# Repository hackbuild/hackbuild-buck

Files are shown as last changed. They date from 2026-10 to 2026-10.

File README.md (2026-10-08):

# BUCK

A 3D printed talking deer head. Send it text from anywhere and it says it out loud, moving its jaw in time with the vowels.

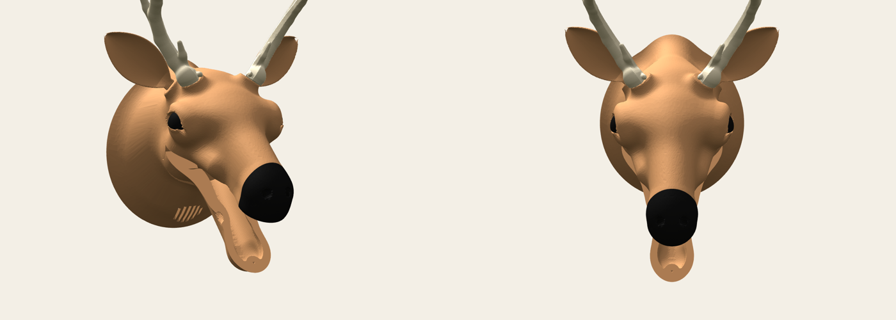
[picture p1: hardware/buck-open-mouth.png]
BUCK with its mouth open


BUCK runs on an ESP32-C3 SuperMini with a 9 g servo for the jaw and a small I2S amp. The voice is SAM, the 1982 Software Automatic Mouth, rendered on the chip. Messages come in over USB serial, [CLASP](https://clasp.to), or MQTT, and anyone with curl can make it talk.

One of them hangs on the wall at [HeatSync Labs](https://www.heatsynclabs.org) in Mesa, Arizona. This repo has everything to talk to that one, and everything to print, wire, and program your own.

## Talk to the BUCK at HeatSync

From a terminal, with the curl that ships on macOS and most Linux distros:

```
curl -d "hello from the internet" mqtt://relay.clasp.chat/hackbuild/buck/heatsync/say
```

From a browser: [hackbuild.github.io/hackbuild-buck](https://hackbuild.github.io/hackbuild-buck/) has a text box, a voice picker, and a live view of what BUCK is saying.

From code, with the [CLASP JavaScript client](https://www.npmjs.com/package/@clasp-to/core):

```js
import { Clasp } from '@clasp-to/core';
const buck = new Clasp('wss://relay.clasp.to', { name: 'my app' });
await buck.connect();
buck.emit('/hackbuild/buck/heatsync/say', 'hello deer');
```

From Python, with nothing to install:

```
python3 tools/buck.py say "hello deer"
python3 tools/buck.py say "hello deer" --voice robot
python3 tools/buck.py watch
```

A few things to know before you send:

- BUCK takes 200 characters per message. Longer text is cut.
- It takes four messages at once, then one every three seconds. Extra messages are dropped, not queued.
- Plain English works best. Numbers are read digit by digit, so "10" comes out as "one zero".
- Voices are `sam`, `elf`, `robot`, `stuffy`, `oldlady`, and `et`. Send one to `/hackbuild/buck/heatsync/voice`.
- It is a deer on a wall in a room full of people. Be someone they would want to hear from.

The HeatSync BUCK also announces the lab calendar: an hour before each event, and at 9:30 and 9:45 PM before closing. That runs separately, in [hackbuild/buck-announcer](https://github.com/hackbuild/buck-announcer).

[docs/PROTOCOL.md](docs/PROTOCOL.md) has every address, payload, status value, and limit, with examples for curl, mosquitto, Python, JavaScript, and raw CLASP frames.

## Build your own

You need a 3D printer, about 240 g of PETG, an ESP32-C3 SuperMini, an SG90 servo, the NULLLAB NS4168 amp kit, a USB-C charger, and a soldering iron. [docs/BUILD.md](docs/BUILD.md) walks through the whole thing:

1. Print the parts from `hardware/`. Nothing needs supports.
2. Wire the board, servo, and amp. Five wires and two components.
3. Flash the firmware with [PlatformIO](https://platformio.org).
4. Set WiFi and a name over serial.
5. Calibrate the jaw.

Your BUCK gets its own address, `hackbuild/buck/<your id>/say`, on the same public relays, so it works from anywhere the moment it joins WiFi.

## What is in here

```
src/            firmware: speech, jaw, console, network links
lib/buckproto/  CLASP and MQTT codecs and the text filter, no Arduino, unit tested
lib/sam/        SAM speech synth, with a hook that drives the jaw
test/           host tests: pio test -e native
tools/buck.py   send, watch, and serial console from your computer
web/            the talk page published to GitHub Pages
hardware/       STL and 3MF print files, print card, the BUCK bench design tool
docs/           BUILD.md, PROTOCOL.md, FIRMWARE.md
```

[docs/FIRMWARE.md](docs/FIRMWARE.md) covers how the firmware is put together: the four tasks, how the jaw reads SAM's formants, what happens when WiFi drops or the board crashes, and every serial command.

## License

The firmware links SAM, which is GPL-3.0, so this repository is GPL-3.0. See [LICENSE](LICENSE). SAM is by Don't Ask Software (1982), reverse engineered to C by Sebastian Macke, and ported to the ESP8266 and ESP32 by Earle F. Philhower III.

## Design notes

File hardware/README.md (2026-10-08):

# Print files

| file | what it is |
|---|---|
| `buck-plates-3mf.zip` | four plates, one per filament: brown (head, jaw, ears), bone (antlers), black (nose, eyes), walnut (plaque, hooks, pivot pin) |
| `buck-one-colour.3mf` | every part on one 256 x 256 bed for a single filament |
| `buck-stl.zip` | each part as a single body STL, plus `print-card.txt` and `design.json` |
| `print-card.txt` | orientation, fits, hardware, and assembly on one page |
| `design.json` | the BUCK bench settings these files came from; load it in the bench to start from this head |
| `buck-bench.html` | the BUCK bench design tool, one offline HTML file: shape the head, check the fit audit, export plates |
| `source/buck-bench-src.zip` | the bench's source (`build.py` assembles `buck-bench.html`) |
| `buck-open-mouth.png` | render of the finished head |

The print card's wiring section lists an ESP32-S3 SuperMini pinout. This repo's firmware runs on the ESP32-C3 SuperMini, which has the same footprint; wire it as shown in [docs/BUILD.md](../docs/BUILD.md).

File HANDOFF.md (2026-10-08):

# buck, handoff

## what it is

A 3D printed talking deer head. ESP32-C3 SuperMini, SG90 jaw servo, NULLLAB NS4168 I2S amp. Text arrives over USB serial, CLASP over WebSocket, or MQTT; SAM speaks it on the chip and the jaw follows each frame's first formant. One hangs at HeatSync Labs and anyone can make it talk with curl.

Read `RULES.md` first. It is absolute and wins over this file.

## deployments

| what | where |
|---|---|
| repo | https://github.com/hackbuild/hackbuild-buck |
| talk page | https://hackbuild.github.io/hackbuild-buck/ (GitHub Pages, `web/`, `.github/workflows/pages.yml`) |
| the HeatSync head | id `heatsync`, WiFi `heatsynclabs`, flashed from the `heatsync` env on 2026-10-07 |
| CLASP door | `wss://relay.clasp.to`, open, no MQTT (DigitalOcean App Platform behind Cloudflare) |
| MQTT door | `relay.clasp.chat:1883`, open; its CLASP WebSocket side needs a token |
| curl | `curl -d "hello" mqtt://relay.clasp.chat/hackbuild/buck/heatsync/say` |
| calendar announcements | https://github.com/hackbuild/buck-announcer, a Cloudflare Worker that sends lines to this head over CLASP; verified on the head 2026-10-07 |

## where it stands, 2026-10-07

Firmware 1.2.0 is on the HeatSync head and verified on the HeatSync WiFi:

- curl over MQTT, `tools/buck.py` over MQTT and CLASP, and the `@clasp-to/core` 4.3.2 SDK all made it speak; the talk page loaded and showed live status
- after seven idle minutes, messages still arrived on both links (this failed before the heartbeat; see "things found in CLASP")
- heartbeats come back on both links every 45 s
- a 14 second line full of phone numbers played to the end (the reciter split)
- status (`online`, `speaking`, `said`, `info`) reached subscribers on both relays, late joiners included; the jaw stream ran at about 15 Hz
- the rate limiter passed 4 of a burst of 6
- 20 host tests pass, including 200,000 random frames through the CLASP decoder; CI builds both environments on every push

1.2.0 fixes the crash a line of the letter o caused: SAM's `InsertBreath` looped forever on a long word, starving the network until the watchdog rebooted the board. Fuzzing SAM under AddressSanitizer then found five more hangs and overruns in it. All are fixed (`lib/sam/README.md` lists them), `test/test_sam` keeps them fixed, 80,000 random lines ran clean on the host, and 60 and 200 o's now play on the head.

An independent review of the firmware found ten problems, all fixed in the same pass: reciter overflow cutting off the ends of lines, watchdog overrun on weak WiFi, safe mode that never recovered, a fragile MQTT heartbeat probe, `speaking` dropping early, oversize messages discarded instead of cut, a tripled backoff on one failed send, a servo cache that skipped writes after `/release`, a jaw jump out of a hold, and a possible synth stall.

The head's voice is back on the defaults, `sam` (speed 72, pitch 64), as of 2026-10-08.

The head's saved volume is 30. On the bench it runs from a bus powered USB hub, and at 50 it browned out at the first syllable of every line; at 30 a 14 second sentence played clean. On a 1 A charger with the servo capacitor it should take 50 or more: `/vol 50`.

## decisions and why

- Two relays. relay.clasp.to is the only open CLASP WebSocket relay; relay.clasp.chat is the only one with MQTT open, and curl speaks MQTT. Guest tokens on relay.clasp.chat are scoped to `/chat/**`, so one relay could not serve both. curl over `wss://` cannot work: the relay drops PUBLISH before HELLO and reads one frame per WebSocket message.
- Own WebSocket client and codecs. The CLASP Arduino library (`bindings/arduino`, 1.0.0, on every branch, unpublished) speaks TCP only, and the relays only take WebSocket. The codec follows `crates/clasp-core/src/codec.rs`, with test vectors captured from the live relay.
- Heartbeat on both links. Because of the idle-session bug above, each link publishes `status/beat` every 45 s and expects it back through its own subscription; 140 s without one means reconnect. CLASP gets the beat back through the SET echo. MQTT does not echo, so a short lived second connection publishes the beat. Keepalive pings cannot catch the bug: the relay answers them the whole time.
- Ignore replays. relay.clasp.chat replays every stored MQTT topic before SUBACK with retain cleared, so BUCK skips anything on a topic until its SUBACK. CLASP snapshots are skipped too.
- ESP32-C3, not S3. The print card and bench say S3 SuperMini; the board on the wall is a C3 (esptool says so), wired servo 4, BCLK 5, LRCLK 6, DIN 7.
- Jaw calibration on the HeatSync head: it was assembled at the servo's end stop with the jaw fully open. The BUCK geometry (shaft out the right cheek, jaw opens clockwise looking at the shaft) put open at the short-pulse end. Probing with single pulses (at most about 12 degrees each, under the 22 degree swing) confirmed it, and closed was found from the open side in small steps. Result: open 500 us, closed 730 us.
- Talking stops 10 us short of closed. Driving the servo into the contact point stalls it and browned out the board on USB power.
- WiFi TX power 8.5 dBm. Cuts radio bursts from about 300 mA, and is the known fix for the SuperMini's antenna. Full power plus servo plus amp browned out the board.
- Network settings save and reboot instead of applying live, so no task ever reads a half written string.
- GPL-3.0 for the whole repo, because SAM is GPL.

## open questions

- Anyone on the internet can make the head say anything. The rate limit stops floods, not words. A word filter, an allow list, or `/remote off` during events are options; nothing is filtered now. This is a call for HeatSync.
- The head runs off a bus powered USB hub on the bench. On the wall it needs a 1 A charger. The 10 k pull-down on GPIO4 and the servo capacitor may not be fitted yet; both are in docs/BUILD.md.
- An HTTP bridge on relay.clasp.to (`clasp http`, `POST /v1/emit/...`) would allow a plain `curl -X POST https://...` that works without MQTT. Today the relay answers every HTTP path with `ok`.

## things found in CLASP along the way

Worth fixing upstream in lumencanvas/clasp:

- Idle sessions lose their subscriptions without being closed. `clasp-router` `start_session_cleanup_task` removes a session idle for `session_timeout` (300 s) and its subscriptions, but never closes the transport, and `last_activity` only moves when the router sends to the client (`Session::send`, `try_send`). Client sends and WebSocket pings do not count. A listener that rarely receives anything goes deaf after five minutes while its socket stays up and pongs keep coming. Both relays showed it: BUCK heard nothing for 48 minutes on 2026-10-07 with both links "ready". The fix belongs in the router: close the transport when a session times out, and count inbound traffic as activity.
- relay.clasp.chat's MQTT side never delivers a client's own publishes back to it.
- relay.clasp.chat's MQTT bridge stores non-retained publishes and replays them before SUBACK with the retain flag cleared.
- docs.clasp.to's LLM reference shows `subscribe` callbacks as `(address, value)`; `client.ts` has `(value, address)`.
- The protocol doc's SET example says payload length 0x1B; its own bytes are 26 (0x1A).
- `clasp pub` 4.5.0 prints "OK Published" and then logs "Server connection not yet implemented".
- The Arduino library's value codes differ from the protocol doc's (bool as 0x01 plus a byte), though they match the Rust codec.

## this machine

- PlatformIO Core was upgraded to 6.2.0; pioarduino 55.03.312-1 needs it.
- The disk was full during the first build. `~/.platformio/packages/framework-arduinoespressif32-libs` holds only the `esp32c3` and `hosted` folders of core 3.3.12's libs, marked installed by hand. Building for any other ESP32 with this platform will fail until it is reinstalled with space free: `pio pkg uninstall -g -t framework-arduinoespressif32-libs`, then build again.
- The CLASP source checked out at `~/Projects/lumencanvas/clasp` (branch relay-scaling) is where the relay, codec and Arduino library were read from.

## running locally

```
pio test -e native                         # host tests, must pass before a commit
pio run -e buck -e heatsync                # both firmware builds, must pass before a commit
pio run -e heatsync -t upload              # flash the HeatSync head
pio device monitor                         # serial console
python3 tools/buck.py say "hi"             # MQTT, stdlib only
python3 tools/buck.py watch --via clasp    # needs websockets
```

Opening the C3's USB serial with RTS high and DTR low resets it. `tools/buck.py console` holds RTS low.

Before flashing an assembled head, park the jaw part open with `/jaw 50`. The reset during upload drives the servo line high briefly, which pushes toward closed.

## commits

Author is Moheeb Zara <hackbuildvideo@gmail.com>. No trailers, no AI attribution, imperative lowercase subjects under 60 characters. See `RULES.md`.

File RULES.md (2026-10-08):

# Rules for working in this repository

These rules are absolute. They apply to every file, every commit, and every generated string, including code comments, serial log lines, status strings, and the web page. Where any other document disagrees with this one, this one wins.

## Attribution

- Never add Claude, any AI assistant, or any AI tool as an author, co-author, contributor, or credit of any kind. Not in commit messages, not in Co-Authored-By trailers, not in comments, not in documentation.
- Commit messages carry no trailers, no badges, no generated-with lines. Subject in the imperative, lowercase, under 60 characters. Body only when the change needs explaining, wrapped at 72 columns.
- Author is Moheeb Zara <hackbuildvideo@gmail.com>.

## Language

- No emojis, anywhere.
- No em dashes or en dashes. Use commas, periods, or the word "to" for ranges.
- No "it is not x, it is y" construction or its variants.
- No closing line that restates the point.
- No exclamation marks in prose, logs, or UI copy.
- No marketing adjectives: seamless, powerful, robust, comprehensive, beautiful, elegant, and their kin. Say what it does.
- No filler openers: "Let's", "Simply", "Just", "Note that".
- Log lines and UI copy are lowercase and terse, and name the failure: "no WiFi set, send: /wifi <ssid> <password>" beats "error".
- Never claim a capability the hardware does not have.

## Firmware

- No heap allocation per message. Buffers are sized at compile time or allocated once at boot.
- Every blocking network call has a deadline.
- Only the player task drives the servo. Only the net task touches sockets.
- The jaw never leaves the calibrated range outside the explicit calibration commands.
- `pio test -e native` and `pio run -e buck -e heatsync` pass before a commit.

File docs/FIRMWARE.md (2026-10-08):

# How the firmware works

BUCK's firmware is Arduino on ESP-IDF, built with PlatformIO for an ESP32-C3 at 160 MHz. The C3 has one core, so everything here is about priorities and bounded work.

## Tasks

```
serial --+
CLASP  --+--> remote gate --> text queue --> synth task --> stream buffer --> player task --> I2S amp
MQTT   --+    (clean, limit)  (8 lines)      (SAM)          (8 KB, 370 ms)    (20 ms blocks)  +-> servo
                                               |                                ^
                                               +--> jaw events, timestamped ----+
                                               +--> "said" event --> net task --> status on both relays
```

| task | priority | stack | job | file |
|---|---|---|---|---|
| player | 5 | 4 KB | stream buffer to I2S, jaw to servo, console jaw commands | `src/speech.cpp` |
| synth | 3 | 8 KB | text to SAM to samples and jaw events | `src/speech.cpp` |
| net | 2 | 8 KB | WiFi, CLASP link, MQTT link, status | `src/net/net.cpp` |
| loop | 1 | 8 KB | serial console | `src/console.cpp` |

The player outranks the synth, and both outrank the network. A TLS handshake or a stalled socket can slow a link down, but it cannot take time from the 20 ms audio blocks. WiFi's own tasks run above all of these, as ESP-IDF sets them.

Only the player task touches the servo. The console asks for jaw moves through a small queue (`jawCommand()`), so nothing ever fights over the LEDC channel.

Only the net task touches sockets. Links, codecs and buffers have one owner and need no locks.

## Speech and the jaw

SAM renders speech in 10 ms frames. Each frame carries the formants that make its sound, and the first formant, F1, tracks how open a real mouth is: high for "ah", low for "ee" and "oo", and lowest for m, b and p. `lib/sam/src/render.c` has one change from upstream, a `samFrameHook` called at the start of every frame with F1 and the voicing amplitude. The synth task turns that into an openness value:

```
voiced frame:    open = clamp((F1 - 6) / (24 - 6)) * clamp(A1 / 13)
unvoiced frame:  open = 0.15     s, sh, f, th, ch
silence:         open = 0        A1 is 0, which also covers the closure of p, t, k
```

Each value is stamped with its sample position in the stream and queued. The player writes 20 ms blocks to I2S, and for each block takes the widest frame due by the end of that block plus `/lead` ms. It smooths that with a 30 ms attack and a 70 ms release and moves the servo.

The I2S DMA holds about 60 ms, so the servo hears about the jaw roughly 60 ms before the speaker plays the sound. That covers the SG90's lag. Every line starts with 60 ms of silence so the first syllable gets the same head start.

While talking, "closed" is 10 us short of the calibrated closed end (`JAW_CLOSED_MARGIN_US`). A servo held exactly at the contact point pushes against the head and draws stall current, which on a USB supply is enough to brown out the board. After 0.6 s of quiet the PWM detaches entirely.

Talking moves are rate limited to 60 us per 20 ms block (`JAW_SLEW_US`), about 5 degrees. That caps the servo's current spikes and turns a jump from a held position into a quick glide.

Everything reaches SAM through `lib/sam/src/sam_say.c`. `samTame` keeps the input to what SAM's reciter knows, caps any repeated character at three ("soooooo" says "sooo") and splits words longer than 14 characters. `samSay` cuts lines into pieces; SAM's reciter quietly stops once its phoneme output passes 120 characters, and every digit is a word, so a phone number fills that fast. It checks where the reciter's end marker landed and, if a piece overflowed, splits it at the space nearest the middle and tries each half.

SAM itself is old C with byte-sized indexes into fixed arrays. A line of the letter o hung the deer on 2026-10-07 (an endless loop in `InsertBreath`), and fuzzing under AddressSanitizer found five more ways to hang or overrun it. All are fixed and listed in `lib/sam/README.md`, and `test/test_sam` runs the same `samTame`/`samSay` path on the host under the sanitizers, with an alarm on every input so a hang fails the test.

The jaw never goes outside the calibrated range during speech, `/jaw` or `/sweep`. Only `/servo` and `/probe`, the calibration tools, can reach the full 500 to 2500 us, and `/servo` glides at about 30 degrees a second.

## Memory

Everything is allocated once, at boot:

| what | size |
|---|---|
| text queue, 8 lines of 400 characters | 3.2 KB |
| audio stream buffer | 8 KB |
| jaw event queue, 128 events | 1 KB |
| SAM working memory | 3.7 KB |
| CLASP link buffers (rx 2 KB, tx 640 B, frame 600 B) | 3.3 KB |
| MQTT link buffers (rx 512 B, tx 512 B) | 1 KB |
| task stacks | 28 KB |

Static RAM use is 49 KB of 320 KB. With WiFi up and a TLS session open, about 95 KB of heap stays free, and the lowest it has been is reported as `minHeap` in `status/info`. No code path allocates per message. The codecs write into caller buffers and point into received frames instead of copying.

The TLS client does allocate when it connects. Before each attempt the CLASP link checks that the largest free block is at least 45 KB and skips the attempt if not, so a fragmented heap delays a reconnect instead of crashing it.

## When things go wrong

| failure | what BUCK does |
|---|---|
| WiFi drops | both links stop; WiFi auto reconnect runs, with a fresh `WiFi.begin` every 30 s; after 20 minutes offline it reboots, once it is quiet |
| relay unreachable or refuses | that link backs off 2 s, 4 s, 8 s and so on up to 2 minutes, plus up to 25 percent jitter; the other link carries on |
| link goes silent | WebSocket ping or MQTT PINGREQ every 20 s when idle; nothing heard for 65 s means reconnect |
| relay drops the subscription but keeps the socket | heartbeat: every 45 s each link sends itself a message through its own subscription (CLASP by SET echo, MQTT from a short lived second connection); no beat back for 140 s means reconnect. Pings cannot catch this, the relay keeps answering them |
| malformed CLASP frame | ignored, link stays up; the decoder checks every length and nesting depth (fuzzed with 200,000 random frames in the tests) |
| malformed MQTT stream | link is dropped and reconnected |
| oversize MQTT packet | read to its end so the stream stays in sync, and delivered cut to the 512 byte buffer; the text is then cut to 200 characters as usual |
| oversize WebSocket message (over 2 KB) | read off the wire and dropped, counted |
| flood of messages | token bucket (4, then 1 per 3 s) and a cap of 4 waiting network lines |
| old messages replayed by a relay | ignored: CLASP snapshots are skipped, MQTT messages before SUBACK are skipped |
| a task hangs | task watchdog, 60 s, on the player, synth, net and loop tasks; the chip resets with a backtrace on serial. Every network connect is bounded at 8 s plus the TLS handshake, and every later socket write at 3 s (plain) or 8 s (TLS), with the watchdog fed between steps |
| crashes in a loop | a counter in RTC memory; three crash resets in a row boot into safe mode with networking off, so serial still works. Five crash-free minutes turn networking back on by themselves; `/reboot` clears the count and boots normally straight away |
| brownout | the chip resets; `status/info` reports `"reset":"brownout"` so it shows up remotely |
| nobody reading USB serial | the CDC TX timeout is zero, so logging never blocks |

## Serial console

115200 baud on the USB port. Lines starting with `/` are commands; anything else is spoken.

| command | does |
|---|---|
| `/vol <0-100>` | volume, saved |
| `/voice <name>` | `sam` `elf` `robot` `stuffy` `oldlady` `et`, saved |
| `/speed` `/pitch` `/throat` `/mouth <1-255>` | SAM's four voice controls, saved |
| `/stop` | cut the current line and clear the queue |
| `/tone [hz] [ms]` | test tone |
| `/jaw <0-100>` | hold the jaw at a percent open for 3 s |
| `/sweep` | closed, open, closed over 3 s |
| `/open <us or deg>` `/closed <us or deg>` | calibration ends; over 180 means microseconds; saved |
| `/lead <ms>` | jaw lead over the sound, default 10, saved |
| `/servo <us>` | glide to a raw pulse and hold it until `/release` or speech |
| `/probe <us> [n]` | n single pulses, then let go |
| `/release` | stop driving the servo |
| `/wifi <ssid> <password>` | save and reboot; the SSID cannot contain spaces, the password can |
| `/id <name>` | 1 to 31 letters, digits, `-` or `_`; save and reboot |
| `/clasp <wss://host or off>` | CLASP relay; save and reboot |
| `/mqtt <host[:port] or off>` | MQTT broker; save and reboot |
| `/tls on or off` | check the relay's certificate (on by default); save and reboot |
| `/remote on or off` | accept network messages; saved |
| `/net` | WiFi and link status, counters |
| `/status` | firmware, calibration, voice, heap |
| `/reboot` `/factory` | restart; wipe saved settings and restart |

Network settings reboot on change because the network task reads them once at start. That keeps a half written string from ever reaching a socket.

## Settings

NVS namespace `buck`. Missing keys fall back to the build defaults in `platformio.ini`.

| key | type | default |
|---|---|---|
| `open` `closed` | int, us | `BUCK_DEFAULT_OPEN_US`, `BUCK_DEFAULT_CLOSED_US`, 0 means uncalibrated |
| `lead` | int, ms | 10 |
| `vol` | int | 50 |
| `voice` | string | `sam` |
| `speed` `pitch` `throat` `mouth` | int | 72, 64, 128, 128 |
| `id` | string | `BUCK_DEFAULT_ID`, else `buck-` and the MAC |
| `ssid` `pass` | string | `BUCK_DEFAULT_SSID`, `BUCK_DEFAULT_PASS` |
| `clasp` | string | `wss://relay.clasp.to` |
| `mqtt` `mqttport` | string, int | `relay.clasp.chat`, 1883 |
| `tls` `remote` | bool | true, true |

## TLS

The CLASP link checks the relay's certificate against the roots in `src/net/ca_roots.h`: Google Trust Services R1, R3 and R4, and ISRG X1 and X2. relay.clasp.to currently chains to GTS Root R4 through Cloudflare. The earliest of these roots expires in 2035. If the relay moves to a CA outside that list, the CLASP link logs a connect failure and MQTT keeps working; add the new root, or `/tls off` as a stopgap.

## Build environments

| env | for |
|---|---|
| `buck` | your own BUCK; nothing preset |
| `heatsync` | the HeatSync Labs head: id `heatsync`, its WiFi, and its jaw calibration (open 500 us, closed 730 us) |
| `native` | host unit tests: `pio test -e native` |

The platform is pinned to pioarduino 55.03.312-1, which is Arduino core 3.3.12 on ESP-IDF 5.5.5, and needs PlatformIO Core 6.2 or newer.

## Power

Peak draw is the amp, the servo and the WiFi radio together, and the amp is the largest part. Measured on the HeatSync head running from a bus powered USB hub: talking at `/vol 50` browned out at the first syllable, the jaw alone at `/vol 0` did not, and `/vol 30` got through a 14 second sentence clean.

The firmware already trims what it can: WiFi transmit power is 8.5 dBm (radio bursts drop from about 300 mA, and the SuperMini's antenna likes it), talking never presses the jaw into its stop, and jaw moves are rate limited. The rest is hardware: a USB charger of 1 A or more and a 470 to 1000 uF capacitor at the servo. On weak power, keep `/vol` around 30.

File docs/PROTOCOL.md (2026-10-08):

# Talking to BUCK

Every BUCK listens on two public relays at once and reports what it is doing on both. This page is the full contract: addresses, payloads, limits, and what comes back.

## Two doors, one deer

[CLASP](https://clasp.to) is a signal routing protocol: clients connect to a relay, publish to addresses that look like `/a/b/c`, and subscribe to patterns. BUCK keeps two connections open, one to each of two CLASP relays:

| door | relay | who it is for |
|---|---|---|
| CLASP over WebSocket | `wss://relay.clasp.to` | browsers, the CLASP SDKs, anything that speaks CLASP |
| MQTT 3.1.1 over TCP | `relay.clasp.chat:1883` | curl, mosquitto, any MQTT client |

MQTT stands for Message Queuing Telemetry Transport, a small publish and subscribe protocol that curl happens to speak. The MQTT door is the MQTT bridge built into the CLASP relay, so an MQTT topic `hackbuild/buck/heatsync/say` is the CLASP address `/mqtt/hackbuild/buck/heatsync/say` on that relay.

The two relays are separate routers. A message sent on one is not visible on the other, so pick one door and read status from the same one. Neither needs an account.

## Addresses

Each BUCK has an id. The one at HeatSync Labs is `heatsync`. Yours is whatever you set with `/id`, or `buck-` plus the last six hex digits of its MAC address.

| what | CLASP address (relay.clasp.to) | MQTT topic (relay.clasp.chat) |
|---|---|---|
| say something | `/hackbuild/buck/<id>/say` | `hackbuild/buck/<id>/say` |
| change voice | `/hackbuild/buck/<id>/voice` | `hackbuild/buck/<id>/voice` |
| status | `/hackbuild/buck/<id>/status/...` | `hackbuild/buck/<id>/status/...` |

## Sending

### say

The payload is the text. In CLASP, send it as a string, either as an event (`emit`) or a param (`set`); BUCK treats both the same, and a number is read out as a number. In MQTT, the payload bytes are the text.

```
curl -d "hello deer" mqtt://relay.clasp.chat/hackbuild/buck/heatsync/say
mosquitto_pub -h relay.clasp.chat -t hackbuild/buck/heatsync/say -m "hello deer"
python3 tools/buck.py say "hello deer"
python3 tools/buck.py say "hello deer" --via clasp
```

```js
// @clasp-to/core 4.3.2, Node or browser
const buck = new Clasp('wss://relay.clasp.to', { name: 'my app' });
await buck.connect();
buck.emit('/hackbuild/buck/heatsync/say', 'hello deer');
```

### voice

The payload is one of `sam`, `elf`, `robot`, `stuffy`, `oldlady`, `et`. Anything else is ignored. A voice set over the network lasts until BUCK reboots; a voice set over serial is saved.

```
curl -d "robot" mqtt://relay.clasp.chat/hackbuild/buck/heatsync/voice
```

### What BUCK does with your text

1. Cleans it: curly quotes become straight ones, emoji and other non-ASCII become spaces, whitespace collapses. Before speaking, a character repeated more than three times is cut to three ("noooooo" says "nooo") and a word longer than 14 characters is split.
2. Cuts it to 200 characters. Over MQTT any length is accepted and cut; over CLASP a frame larger than 2 KB is ignored.
3. Checks the rate limit: a bucket of four messages, refilled at one every three seconds, shared by everyone on both doors.
4. Checks the queue: at most four network messages wait at once.
5. Speaks it, after whatever is already queued.

A message that fails step 3 or 4 is dropped. There is no reply; watch `status/said` to see what made it.

SAM reads English spelling with its own rules from 1982. Short sentences with ordinary words sound best. Digits are read one at a time, so write numbers as words. Punctuation shapes the intonation: a period drops the pitch, a question mark raises it.

## Status

BUCK publishes these whenever they change. On relay.clasp.to they are CLASP params, and on relay.clasp.chat they are MQTT messages with the retain flag. Either way the relay stores the last value, so anyone subscribing late gets the current state straight away.

| leaf | type | meaning |
|---|---|---|
| `status/online` | bool | `true` when the link comes up. MQTT also sets a will of `false`, so the broker flips it if BUCK vanishes. CLASP has no will, so check `info` for freshness |
| `status/speaking` | bool | talking right now |
| `status/said` | string | the line it started speaking most recently |
| `status/info` | string, JSON | refreshed every 60 s, see below |
| `status/jaw` | float 0 to 1, CLASP stream | jaw openness about 15 times a second while talking, then a final 0. Not stored, CLASP only |
| `status/beat` | int (CLASP) or text (MQTT) | BUCK's heartbeat, every 45 s: seconds since boot. See "staying subscribed" below |

`info` looks like this:

```json
{"fw":"1.2.0","id":"heatsync","up":3600,"heap":94816,"minHeap":74560,"rssi":-54,
 "reset":"power","crashes":0,"queue":0,"heard":42,"limited":3,"voice":"sam",
 "clasp":"ready","mqtt":"ready"}
```

`up` is seconds since boot. `clasp` and `mqtt` are the state of each link: `ready`, `handshake`, `waiting` (backing off before a retry), or `off`. `reset` is why it last booted: `power`, `restart`, `usb`, `brownout`, `panic`, `task-wdt`, and a few rarer ones. `heard` and `limited` count network messages since boot.

Watch status:

```
python3 tools/buck.py watch                  # MQTT
python3 tools/buck.py watch --via clasp      # CLASP, needs: pip install websockets
mosquitto_sub -h relay.clasp.chat -t 'hackbuild/buck/heatsync/status/#' -v
```

```js
buck.on('/hackbuild/buck/heatsync/status/**', (value, address) => {
  console.log(address, value);
});
```

The CLASP callback gets `(value, address)` in that order.

## On the wire

You do not need this to use BUCK. It is here for anyone writing a client from scratch.

CLASP v3 frames are binary. Each WebSocket message carries exactly one frame, and the WebSocket subprotocol is `clasp`.

```
53            magic 'S'
41            flags: QoS 1 (bits 7-6), binary encoding (bits 2-0 = 1)
00 2e         payload length, big endian
...           payload
```

A client sends HELLO first and waits for WELCOME:

```
53 41 00 0d   01 01 e0   00 06 "my app"   00 00
              HELLO, version 1, features param+event+stream, name, empty token
```

Then an event with a string value:

```
53 41 00 2e   20 20   00 1c "/hackbuild/buck/heatsync/say"   01 08 00 0a "hello deer"
              PUBLISH, signal event (1 << 5), address, has value, string, text
```

The relay drops a PUBLISH that arrives before HELLO. It also reads one frame per WebSocket message, so two frames in one message lose the second. That rules out sending CLASP straight from `curl wss://`, which is why the curl examples use the MQTT door.

The full codec BUCK uses is `lib/buckproto/src/clasp_codec.cpp`, and `test/test_protocols` has frames captured from relay.clasp.to.

## Staying subscribed

The relays drop a session's subscriptions after five minutes in which the relay has sent that client nothing, and they do it without closing the socket. Pings keep getting answered, so the client looks connected and hears nothing. A listener that rarely gets messages, which is exactly what a deer on a wall is, falls into this.

BUCK guards against it with a heartbeat on each link. Every 45 s it publishes to its own `status/beat` and listens for that message to come back through its subscription:

- on CLASP, the relay echoes a SET to every subscriber of the address, the sender included
- on MQTT, the relay never sends a client its own publishes, so BUCK opens a second, short lived connection, publishes the beat from there, and disconnects

Either way the relay has something to deliver to BUCK every 45 s, which keeps the session active, and the delivery proves the subscription works end to end. If no beat comes back for 140 s, BUCK drops that link and reconnects.

Clients of your own that only listen should do the same, or reconnect every few minutes.

## Relay behaviour worth knowing

- On relay.clasp.chat every MQTT publish is stored, retained or not, and replayed to new subscribers before their SUBACK, with the retain flag cleared. BUCK ignores anything on a topic until its SUBACK arrives, so old messages are never spoken again after a reconnect.
- On relay.clasp.to a CLASP subscriber gets a SNAPSHOT of stored params first. BUCK ignores snapshots for the same reason.
- relay.clasp.chat requires a token for CLASP over WebSocket, and its guest tokens are scoped to `/chat/**`. That is why CLASP clients use relay.clasp.to.

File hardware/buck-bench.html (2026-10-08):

# BUCK.bench

talking trophy head. servo jaw. printed everything else. undo redo open save guide

1HEAD 2GUTS 3MOUNT 4PRINT

STEP 1 HEAD

isofrontsidetopunder

assembledexplodeprint bedpaintx-raysectionhardwarepegboard

BUILDING

CUT X0

prevplate 1next

JAW0 deg talkmicwiggle

## BUCK.bench

a talking white-tail trophy you print, wire and hang on pegboard. an SG90 servo swings the jaw; an ESP32-S3 or RP2040-Zero and the NULLLAB NS4168 kit (amp and its 3W speaker) do the talking from inside the neck; one USB-C cable runs out the back. everything else is printed: eyes, nose, ears, antlers, pivot pin and pegboard hooks. every part is one material, so print each in its own filament or print it all in one and paint it.

1 head

sculpt, eyes, nose, ears, antlers

2 guts

servo jaw, boards, speaker, wiring

3 mount

plaque, edge, pegboard hooks, head screws

4 print

fit audit, filaments, plates, 3MF

pick a starting point; every change rebuilds the parts and reruns the fit audit.

8 point buckfork hornspikedoe

### SCULPT

scalex

muzzlex

neckx

crownx

cheeksx

nose downdeg

wallmm

sculpt changes regrow the skin from its field, a few seconds. the audit tells you if the servo still fits.

### EYES + NOSE

eyes

separatesculpted

eye sizex

eye fitmm

nose

separatesculpted

nose fitmm

separate eyes are almond domes that press into sockets inside the lids; print them in black for a real shine. sculpted puts them in the head for painting. fit is the designed clearance per side; holes print about 0.15 small, so 0.10 gives a light press.

### ANTLERS

nonespikefork8 point

sizex

spreadx

round on top and 45 degrees underneath, so they print flat with no supports and still look round. keyed tenons press into the pedicles.

### EARS

ears

sizex

ears print lying on their flat backs, cup up: the back is a flat plane with a steep bevel to the rim, and the tenon runs down to the bed, so nothing hangs in the air.

next: guts

### JAW

swingdeg

clearancemm

jaw

channelsealedsolid

jaw wallmm

channel: the lower jaw is an even skin opened through the mouth like a real one, a U trough with a thicker lip rim and the tongue groove down the middle (about 47 percent less plastic). sealed keeps a solid mouth face over a closed void. both print mouth face down with no support: the trough floor is tented at 45 degrees to an 8 mm bridge. the hinge, arms, horn groove and pin bore stay solid.

the jaw rides the servo horn on the right and a printed pivot pin on the left, both on one axis. it slides up through the mouth onto the horn, then the pin pushes in through the left cheek and clicks. no screws: the arm's groove keeps the horn on the spline.

### BOARDS

controller

custom l w t

the controller sticks onto a plinth on the left face of the fin with foam tape or hot glue. the plinth is 9 mm wide, narrower than the pin rows, so every pin and edge pad stays free to solder. its USB-C faces the plaque and lines up with the cable slot.

i2s amp: NULLLAB NS4168, 38.4 x 22.4 from the vendor drawing. it lies flat on a shelf above the speaker on two posts whose spigots fill its 4.7 mm holes, held by two M3 x 6 screws. it slides in from the servo horn side, input connector first, so the fin over it is cut back only where that end passes.

### SPEAKER

framemm

ear spanmm

depthmm

conemm

dome proudmm

ear holemm

the kit speaker lies face down on a seat ring in the bottom of the neck and fires down through a grille in the throat. its ears screw to two bosses with M2 pilots. these sizes come off the listing photo, not calipers: measure yours and set frame, ear span and depth, and the seat, bosses and shelf follow.

### WIRING

pins are a suggestion; any free GPIO works. on an S3 keep off strapping pins 0, 3, 45 and 46. the amp's input is the 5 pin PH2.0 lead from the kit: G, V, BCLK, LRCLK, DIN.

next: mount

### PLAQUE

shieldovalrounded

edge

ogeeroundchamfersquare

thicknessmm

neck fillof width

routed line

head on

3 screwssnap

snap overlapmm

the plaque is sized off the neck: neck fill is how much of the plaque width the neck takes. the edge profile is cut in whole layers so it prints exactly.

3 screws: the head slides over the locating lip and three M3 x 16 flat head screws go in from the back of the plaque, countersunk flush, into bosses inside the neck rim (one top, two low). to take the head off, slide the plaque off its hooks and undo three screws. snap: the old two bead snap, no hardware, less secure.

### PEGBOARD

hang with

printed hooksstore peghooksnone

board

1/4 in1/8 in

spacingin

holemm

keyholes

printed hooks are curved prongs: hold one tilted up, put the tip in a hole and roll it down, and it locks behind the board. do two, a whole number of inches apart, then slide the plaque's back channel onto both from the side. the head's weight winds them tighter.

next: print

### FIT AUDIT

### FILAMENTS

print as

per filamentone colour

head, jaw, ears

antlers

eyes

nose

plaque

pin, hooks

per filament: one 3MF per spool, each a plate you print on its own. one colour: everything packed onto as few plates as possible, then paint; the paint view is your guide.

### PRINT

draft meshfine mesh

layermm

bedxmm

slicer profile

write filaments

printer

process

preset

names only, never settings. blank leaves the slicer's selection alone.

no supports anywhere: head rim down, jaw on its mouth, plaque on its back, nose on its cut face, eyes on their backs, ears lying cup up, antlers, pin and hooks flat. parts are nested on their real footprints, so in one colour mode everything goes on a single 256 bed. exports always use the fine mesh.

### EXPORT

3MF plates3MF per partSTL zipprint cardpaint guide

### PARTS

### HARDWARE

### ASSEMBLY

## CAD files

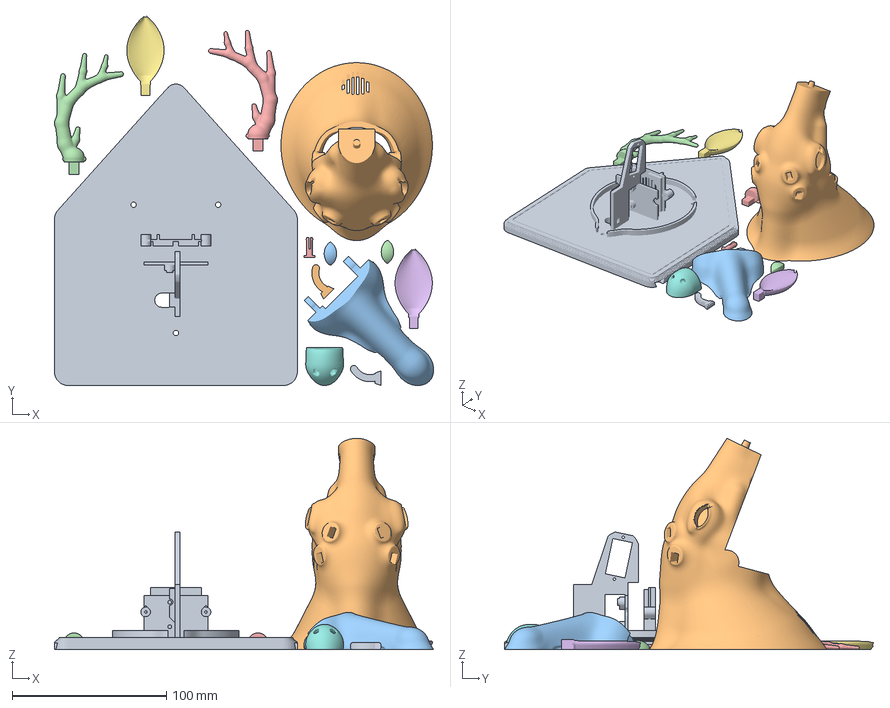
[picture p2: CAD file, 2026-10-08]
hardware/buck-one-colour.3mf
246.0 x 239.3 x 137.0 mm
mount
head
jaw
antler R
antler L
ear R
ear L
nose
hook L
hook R
eye R
eye L
pivot pin

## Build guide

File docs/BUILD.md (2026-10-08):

# Build your own BUCK

Print a deer, give it a voice, and let the internet talk through it.

## Introduction

BUCK is a white-tail trophy head that talks. You print it in four colours of PETG, drop in a microcontroller, a servo, and a tiny amp, and hang it on pegboard. Text you send it comes out of its mouth in SAM's 1982 robot voice, and the jaw moves with the vowels.

In this guide we'll print the parts, wire the electronics, flash the firmware, connect it to WiFi, and calibrate the jaw so it opens and closes in the right places. Plan on a weekend: most of it is print time.

## Prerequisites

Tools:

- A 3D printer with a bed of at least 256 x 256 mm (or print the plates in more pieces)
- A soldering iron and a little solder
- A small Phillips screwdriver
- A computer with [PlatformIO](https://platformio.org), either the VS Code extension or the `pio` command line, Core 6.2 or newer
- About 6 GB of free disk space for the first PlatformIO build

Parts:

| qty | part | notes |
|---|---|---|
| 1 | ESP32-C3 SuperMini | the USB-C one with 8 pins down each side |
| 1 | SG90 or MG90S 9 g servo | with its single arm horn and two mounting screws |
| 1 | NULLLAB NS4168 I2S amp, 3 W kit | comes with the speaker and PH2.0 leads |
| 1 | the kit speaker | 30 mm square frame, ears 39 mm apart, 7.5 mm deep |
| 1 | 470 to 1000 uF electrolytic capacitor, 10 V or more | across the servo power |
| 1 | 10 k resistor | GPIO4 to ground, keeps the jaw still while the board boots |
| 2 | M3 x 6 screws and washers | hold the amp |
| 2 | M2 x 6 self tapping screws (or #2 x 1/4 in) | hold the speaker |
| 3 | M3 x 16 flat head screws (or #4 x 5/8 in wood screws) | hold the head to the plaque |
| 1 | USB-C cable that carries data | |
| 1 | USB charger, 5 V at 1 A or more | a laptop port browns out when the servo and amp peak together |
| | hookup wire | |

Filament, all PETG at 40 percent infill: about 80 g brown, 6 g bone, 5 g black, and 148 g walnut. Any four colours work, or print it all in one colour and paint it.

## Print the parts

Everything is in `hardware/`:

| file | what it is |
|---|---|
| `buck-plates-3mf.zip` | four plates, one per filament colour, ready for OrcaSlicer and its relatives |
| `buck-one-colour.3mf` | every part on one bed, for a single filament |
| `buck-stl.zip` | each part as its own STL, if your slicer drops the 3MF colours |
| `print-card.txt` | orientations, fits, and hardware in one page |
| `buck-bench.html` | the BUCK bench design tool, opens offline in a browser |

1. Open the plates in your slicer. They were set up for a Flashforge Creator 5 Pro with a 0.4 mm nozzle at 0.24 mm layers, but nothing about them is printer specific.
2. Print them. No part needs supports: the head prints on its neck rim, the jaw on its mouth face, and the plaque on its flat back.
3. Check the fits once they cool. The eyes press in with 0.1 mm of clearance, the nose cap onto its peg, and the ears and antlers into keyed sockets. A drop of CA glue fixes anything loose.

If you want a bigger head, a different jaw swing, or a speaker you measured yourself, open `buck-bench.html`, change the sliders, and export new plates. The fit audit re-runs on every change.

## Wire it up on the bench first

Wire and test everything on the table before it goes inside the head. It is a lot easier to fix a swapped wire now.

Hold the SuperMini with the USB-C port at the top and read the pins off the silk:

```
                 USB-C
          5    [       ]  5V
          6    [       ]  G
          7    [       ]  3V3
          8    [       ]  4
          9    [       ]  3
          10   [       ]  2
          20   [       ]  1
          21   [       ]  0
```

| from | to |
|---|---|
| servo orange (signal) | GPIO4 |
| servo red | 5V |
| servo brown | G |
| amp V | 5V (the pad takes two wires, the amp's and the servo's) |
| amp G | G (two wires here too) |
| amp BCLK | GPIO5 |
| amp LRCLK | GPIO6 |
| amp DIN | GPIO7 |
| speaker | its PH2.0 plug into the amp's output |
| 10 k resistor | GPIO4 to G |
| capacitor | across servo red and brown, at the servo end, stripe to brown |

A few rules for this board:

- Leave GPIO2, 8 and 9 alone. They are strapping pins, 8 drives the onboard LED, and 9 is the BOOT button. GPIO20 and 21 are the serial port.
- The amp output is bridge tied. Never connect either speaker wire to ground.
- The BUCK print card lists a pinout for an ESP32-S3 SuperMini. The C3 uses the table above.

The resistor matters more than it looks. GPIO4 to 7 come out of reset pulled up, because they double as the C3's JTAG pins. Until the firmware starts, a high servo line drives the jaw toward closed, and if the board ever sits in its bootloader the servo keeps pushing. The resistor holds the line low.

## Flash the firmware

1. Clone this repo and open it in PlatformIO.

   ```
   git clone https://github.com/hackbuild/hackbuild-buck
   cd hackbuild-buck
   ```

2. Plug the SuperMini in and flash the `buck` environment.

   ```
   pio run -e buck -t upload
   ```

   The first build downloads the ESP32 toolchain and Arduino core 3.3.12 through the [pioarduino](https://github.com/pioarduino/platform-espressif32) platform, which takes a while. If the upload cannot find or sync the port, hold BOOT, tap RESET, release BOOT, and run it again.

3. Open the serial console.

   ```
   pio device monitor
   ```

   You should see the banner:

   ```
   [buck] BUCK 1.2.0 on ESP32-C3, id buck-4fb4c3, reset: usb
   [buck] jaw not calibrated: it stays still until /open and /closed are set
   [buck] type a line to hear it, /help for commands
   [net] no WiFi set, send: /wifi <ssid> <password>
   ```

4. Type `hello` and press enter. The speaker should say it. The jaw stays still until we calibrate it.

`python3 tools/buck.py console` is a serial console too, if you would rather not use PlatformIO's.

## Connect it to WiFi

Send your network and a name. Each one saves and reboots.

```
/wifi MyNetwork my-password
/id mydeer
```

The C3 only sees 2.4 GHz networks. After the reboot, `/net` shows both links:

```
[net] wifi MyNetwork 192.168.1.40 rssi -55
[net] clasp ready wss://relay.clasp.to  connects 1 rx 6 tx 8
[net] mqtt  ready relay.clasp.chat:1883  connects 1 rx 3 tx 6
```

From any computer, it now answers to:

```
curl -d "hello deer" mqtt://relay.clasp.chat/hackbuild/buck/mydeer/say
```

The ids share one public namespace, so pick something nobody else would. `heatsync` is taken.

## Put it together

1. Press the eyes into their sockets, pointed corner toward the nose, then press the nose cap onto the muzzle peg.
2. Press the ears and antlers into their keyed sockets.
3. Screw the servo to the fin with its own two screws, gear tower toward the right cheek. Leave the horn off.
4. Slide the speaker in under the amp shelf from the right side, face down. Lift it over the seat ring, push it back against the stop, drop it, and screw both ears down.
5. Slide the amp in from the same side, components up, input connector first. Drop it onto the two spigots, screw it down with the M3 x 6 screws and washers, and plug in the speaker.
6. Stick the SuperMini onto the plinth on the left face of the fin, USB toward the plaque, with foam tape or hot glue. Route the wires through the slot in the fin.
7. Feed the USB-C cable through the plaque slot and lay it in the groove on the back.
8. Slide the head over the fin onto the locating lip and drive the three M3 x 16 screws in from the back until they sit flush.

The horn and jaw go on during calibration, next.

## Calibrate the jaw

The firmware needs two pulse widths: where the jaw is closed and where it is fully open. Until both are set, the servo never moves on its own.

1. Plug BUCK into its charger and open the console. With the horn still off, center the servo:

   ```
   /servo 1500
   ```

   It glides to 1500 us and holds.

2. Reach in through the mouth and press the horn onto the spline pointing forward and down. That is the closed position.

3. Slide the jaw up and back through the mouth so its right arm takes the horn, then push the pivot pin in through the left cheek until it clicks.

4. Save closed, and save open about 22 degrees away:

   ```
   /closed 1500
   /open 1255
   ```

   The jaw opens clockwise when you look at the end of the servo shaft, and on an SG90 that is the shorter pulse. 245 us is about 22 degrees, the swing the head was designed for.

5. Try it.

   ```
   /jaw 50
   /sweep
   ```

   The jaw should drop halfway, then close, open fully, and close again. If it pushes up into the head instead, your servo turns the other way: `/open 1745`.

6. Fine tune. Move `/closed` 10 us at a time until the lips meet, and `/open` until the mouth is as wide as you like. Every value is saved. While talking, the firmware stops 10 us short of closed so the servo never presses against the head.

7. Type a sentence and watch the mouth. If the jaw seems to lag the voice, raise `/lead` (default 10 ms); if it runs ahead, lower it.

If you already put the jaw on at an unknown angle, there is a careful way back. A single servo pulse moves an SG90 at most about 12 degrees, less than the jaw's 22 degree swing, so `/probe <us>` can never jam it. Probe toward the end you think is open and watch which way it twitches, then approach closed from the open side in small `/servo` steps. Opening the jaw only runs it to a stop; going past closed pushes it into the head.

## Hang it

Roll the two printed hooks into 1/4 in pegboard, 4 in apart: hold each one tilted up, put the tip in a hole, and roll it down. Slide the plaque's back channel onto both hooks from the side. The head's weight winds the hooks tighter.

## Testing

From another computer:

```
python3 tools/buck.py say "testing, one, two, three"
python3 tools/buck.py watch
```

`watch` prints `said`, `speaking`, and `info` as they change. If BUCK reboots in the middle of a sentence and `info` shows `"reset":"brownout"`, it needs a stronger power supply or the servo capacitor.

Common problems:

| symptom | likely cause |
|---|---|
| no sound | BCLK, LRCLK and DIN swapped, or amp V not on 5V |
| reboots mid sentence, `reset: brownout` | laptop USB port or hub; use a 1 A charger and fit the capacitor, or turn it down with `/vol 30` |
| jaw buzzes when quiet | it should not: the servo is released 0.6 s after speech. Check `/status` for a held `/servo` |
| jaw creeps when you plug it in | the 10 k pull-down on GPIO4 is missing |
| `/net` shows wifi down | 2.4 GHz only; check `/wifi`; the firmware already uses low TX power for the SuperMini antenna |
| upload cannot find the port | a charge-only USB cable, or hold BOOT, tap RESET, release BOOT |

## What next

You now have a deer that anyone on the internet can make talk. Some ideas:

- Point a CLASP rule at it, so a door sensor or a 3D printer finishing a job makes BUCK announce it.
- Swap SAM for recorded clips and drive the jaw from the audio's loudness.
- Give it a button or a motion sensor and let it greet people as they walk in.

If you build one, we would love to hear it talk. Share it with the [hack.build](https://hack.build) community or open an issue on this repo with a video.

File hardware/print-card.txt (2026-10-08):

BUCK PRINT CARD
========================================
printer : Flashforge Creator 5 Pro 0.4 nozzle
process : 0.24mm Standard @FF C5
layer   : 0.24 mm
mode    : one filament per plate

PLATES
  1. brown (PETG #8A5A36, about 80 g at 40 percent infill): head, jaw, ear R, ear L
  2. bone (PETG #EAE0CA, about 6 g at 40 percent infill): antler R, antler L
  3. black (PETG #1A1A1A, about 5 g at 40 percent infill): nose, eye R, eye L
  4. walnut (PETG #3B2618, about 148 g at 40 percent infill): mount, hook L, hook R, pivot pin

ORIENTATION (no supports anywhere)
  head      : neck rim on the bed
  jaw       : mouth face on the bed
  mount     : flat back on the bed
  nose      : cut face on the bed
  eye R     : flat back on the bed, dome up
  eye L     : flat back on the bed, dome up
  antler R  : flat side on the bed
  antler L  : flat side on the bed
  ear R     : lying on its flat back, cup up
  ear L     : lying on its flat back, cup up
  pivot pin : on its flat
  hook L    : on its side
  hook R    : on its side

FITS
  eyes press into their sockets with 0.10 mm design clearance; a drop of CA if loose
  nose cap presses onto the muzzle peg; ears and antlers press into keyed sockets (0.20 mm per side)
  head slides over the plaque lip (0.5 mm gap) and is held by 3 x M3 x 16 flat head screws from the back into 2.5 mm pilots, 11 mm deep

HARDWARE
  1  SG90 or MG90S 9 g servo, its single arm horn and its two mounting screws (the horn screw is optional)
  1  ESP32-S3 SuperMini, stuck down with foam tape or hot glue
  1  NULLLAB NS4168 I2S amp (3W kit)
  1  the kit speaker: 30 mm square frame, ears 39 mm apart, 7.5 mm deep
  2  M3 x 6 screws for the amp (self tapping, or a machine screw that cuts its own thread), with M3 washers
  2  M2 x 6 self tapping screws for the speaker ears (or #2 x 1/4 in)
  3  M3 x 16 flat head (countersunk) screws, self tapping or machine, to hold the head to the plaque (or #4 x 5/8 in flat head wood screws)
  1  USB-C cable
     hookup wire and the kit's PH2.0 leads

ASSEMBLY
  1. press the eyes into their sockets, pointed corner toward the nose
  2. press the nose cap onto the peg at the end of the muzzle
  3. press the ears and antlers into their keyed sockets
  4. screw the servo to the fin with its own two screws, gear tower toward the right cheek; leave the horn off
  5. slide the speaker in under the amp shelf from the right side (the servo horn side): lift it over the seat ring, push it back against the stop and drop it; screw both ears down through the holes in the shelf
  6. slide the NS4168 in from the same side, components up, input connector leading; drop it onto the two spigots and screw it down with two M3 x 6 and washers, then plug in the speaker lead
  7. stick the controller onto the plinth on the left face of the fin, USB toward the plaque; the plinth is narrower than the pin rows, so every pin stays free. Wire it, and tuck the leads through the slot in the fin
  8. feed the USB-C cable through the plaque slot into the controller and lay it in the groove on the back
  9. slide the head over the fin onto the locating lip, then drive the three M3 x 16 flat head screws in from the back of the plaque until they sit flush. To take the head off later: slide the plaque off its hooks and undo those three screws
  10. drive the servo to its closed angle, reach in through the mouth and press the horn onto the spline pointing forward and down
  11. slide the jaw up and back through the mouth so its right arm takes the horn, then push the pivot pin in through the left cheek until it clicks
  12. roll the two printed hooks into the pegboard 4 inches apart, then slide the plaque onto them from the side

WIRING
  servo signal -> GPIO 7
  servo + -> 5V (USB)
  amp V -> 5V
  amp G, servo - -> GND
  amp BCLK -> GPIO 5
  amp LRCLK -> GPIO 6
  amp DIN -> GPIO 4
  speaker -> its PH2.0 plug into the amp; the output is bridge tied, never tie either leg to GND

fallback if a 3MF imports with one filament: open the STLs from the STL zip instead; every part is a single body.

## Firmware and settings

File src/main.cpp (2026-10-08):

// BUCK: a talking deer head. ESP32-C3 SuperMini, SG90 jaw servo, NS4168 I2S amp.
//
// Text arrives over USB serial, CLASP (WebSocket) or MQTT. SAM speaks it, and the
// jaw follows the first formant of every 10 ms frame. See README.md and docs/.
//
// Tasks, highest priority first:
//   player (5)  stream buffer -> I2S, moves the jaw          speech.cpp
//   synth  (3)  text queue -> SAM -> stream buffer           speech.cpp
//   net    (2)  WiFi, CLASP and MQTT links, status           net/net.cpp
//   loop   (1)  serial console                               console.cpp

#include <Arduino.h>
#include <driver/gpio.h>

#include "config.h"
#include "console.h"
#include "health.h"
#include "log.h"
#include "net/net.h"
#include "settings.h"
#include "speech.h"

// GPIO4 to 7 leave reset with weak pull-ups (they are the C3's JTAG pins). A high
// servo line drives the jaw toward closed, so pull every output low as early as
// the app can run code. A 10k pull-down on GPIO4 covers the bootloader before this.
__attribute__((constructor)) static void earlyPinsLow() {
  const gpio_num_t pins[] = {(gpio_num_t)PIN_SERVO, (gpio_num_t)PIN_BCLK, (gpio_num_t)PIN_LRCLK, (gpio_num_t)PIN_DIN};
  for (gpio_num_t p : pins) {
    gpio_set_level(p, 0);
    gpio_set_direction(p, GPIO_MODE_OUTPUT);
    gpio_set_pull_mode(p, GPIO_PULLDOWN_ONLY);
  }
}

void setup() {
  Serial.begin(115200);
  Serial.setTxTimeoutMs(0);   // never stall when no computer is reading the USB port
  healthBegin();
  settingsLoad();
  speechBegin();

  uint32_t t0 = millis();
  while (!Serial && millis() - t0 < 1500) delay(10);
  consoleBanner();

  netBegin();
  enableLoopWDT();
}

void loop() {
  consolePoll();
  if (healthTick()) netBegin();   // safe mode ended on this pass
  delay(5);
}

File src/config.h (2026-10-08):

// Fixed facts about the hardware, and the defaults a build starts from.
// Anything a person changes at runtime lives in settings.h instead.
#pragma once

#define FW_VERSION "1.2.0"

// Pins on the ESP32-C3 SuperMini. GPIO2, 8 and 9 are strapping pins (8 is the
// onboard LED, 9 is BOOT) and 20/21 are the UART, so none of those are used.
#define PIN_SERVO 4
#define PIN_BCLK 5
#define PIN_LRCLK 6
#define PIN_DIN 7

// Audio. SAM renders 8 bit mono at 22050 Hz; the player works in 20 ms blocks.
#define SAMPLE_RATE 22050
#define BLOCK_SAMPLES 441
#define AUDIO_BUFFER_BYTES 8192   // about 370 ms between the synth and the player

// Text limits. Serial gets the long limit, anything from the network the short one.
#define TEXT_MAX 400
#define REMOTE_TEXT_MAX 200
#define SPEECH_QUEUE_LEN 8
#define REMOTE_QUEUE_MAX 4        // remote lines allowed to wait at once
#define REMOTE_BURST 4            // token bucket shared by every remote sender
#define REMOTE_REFILL_MS 3000

// Jaw shaping from SAM's frame data (README, "how the jaw follows speech").
#define F1_SHUT 6
#define F1_WIDE 24
#define AMP_FULL 13
#define JAW_UNVOICED 0.15f
#define JAW_ATTACK_MS 30
#define JAW_RELEASE_MS 70
#define JAW_CLOSED_MARGIN_US 10  // talking stops this short of the closed end so the jaw never presses (and stalls) against the head
#define JAW_SLEW_US 60             // most a talking jaw moves per 20 ms block, about 5 degrees
#define SERVO_MIN_US 500
#define SERVO_MAX_US 2500

// Build defaults. platformio.ini sets these per environment; empty means "ask".
#ifndef BUCK_DEFAULT_ID
#define BUCK_DEFAULT_ID ""        // empty: buck-<last 3 bytes of the MAC>
#endif
#ifndef BUCK_DEFAULT_SSID
#define BUCK_DEFAULT_SSID ""
#endif
#ifndef BUCK_DEFAULT_PASS
#define BUCK_DEFAULT_PASS ""
#endif
#ifndef BUCK_DEFAULT_OPEN_US
#define BUCK_DEFAULT_OPEN_US 0    // 0: jaw not calibrated, the servo stays still
#endif
#ifndef BUCK_DEFAULT_CLOSED_US
#define BUCK_DEFAULT_CLOSED_US 0
#endif
#ifndef BUCK_DEFAULT_CLASP_URL
#define BUCK_DEFAULT_CLASP_URL "wss://relay.clasp.to"
#endif
#ifndef BUCK_DEFAULT_MQTT_HOST
#define BUCK_DEFAULT_MQTT_HOST "relay.clasp.chat"
#endif
#ifndef BUCK_DEFAULT_MQTT_PORT
#define BUCK_DEFAULT_MQTT_PORT 1883
#endif

// Every address BUCK uses sits under /hackbuild/buck/<id>/ in CLASP and
// hackbuild/buck/<id>/ in MQTT.
#define ADDR_ROOT "hackbuild/buck"

// Network timing.
#define WIFI_RETRY_MS 30000           // re-issue WiFi.begin after this long without a link
#define WIFI_REBOOT_MS (20UL * 60000) // reboot after this long offline, if quiet
#define LINK_CONNECT_TIMEOUT_MS 8000
#define LINK_HANDSHAKE_TIMEOUT_MS 10000
#define LINK_PING_MS 20000
#define LINK_DEAD_MS 65000            // nothing heard for this long: reconnect
// Heartbeat: each link publishes to its own status/beat and listens for the echo.
// The echo is what keeps a relay from expiring the session as idle, and a missing
// echo means the subscription is gone even though the socket still answers pings.
#define BEAT_MS 45000
#define BEAT_DEAD_MS 140000           // about three missed beats: reconnect
#define LINK_BACKOFF_MIN_MS 2000
#define LINK_BACKOFF_MAX_MS 120000
#define INFO_PERIOD_MS 60000
#define JAW_STREAM_MS 66              // jaw position stream rate while talking, ~15 Hz
#define TLS_MIN_HEAP 45000            // skip a TLS connect when the largest free block is smaller

// Crash handling.
#define SAFE_MODE_CRASHES 3           // this many crash resets in a row: boot without networking
#define CRASH_CLEAR_MS (5UL * 60000)  // uptime that clears the crash count
#define WDT_TIMEOUT_MS 60000          // covers a slow DNS lookup plus a TLS handshake

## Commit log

2026-10-08 add the buck print files and bench design tool
    [buck-one-colour.3mf]
2026-10-08 add heartbeats so a relay cannot silently drop a link
    The CLASP relays expire a session's subscriptions after five minutes in
    which they sent the client nothing, and leave the socket open. Pings
    still get answered, so a listener goes deaf without noticing. Each link
    now sends itself a beat through its own subscription every 45 s: CLASP
    through the SET echo, MQTT from a short lived second connection, since
    that relay never echoes a client's own publishes. No beat for 140 s
    means reconnect. Connect and write timeouts are also bounded now, with
    the watchdog fed between steps.
    [links.h]
2026-10-08 fix ten problems found in a firmware review
    Split lines that overflow SAM's reciter so their ends are spoken, keep
    speaking true while the synth is still parsing, never block the synth
    on the jaw queue, cache PWM writes apart from servo position, rate
    limit talking jaw moves, cut oversize MQTT messages instead of dropping
    them, take 2 KB CLASP frames, recover from safe mode on its own and on
    /reboot, and stop a failed send from tripling the backoff.
    [config.h, console.cpp, main.cpp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]
2026-10-08 send on enter and confirm when buck says it
2026-10-08 document heartbeats, power limits and the review fixes
2026-10-08 fix the sam hangs and overruns a line of o's exposed
    A line of the letter o sent InsertBreath into an endless loop and
    starved the network until the watchdog rebooted the board. Fuzzing SAM
    under AddressSanitizer found five more: a lost end marker that made
    PrepareOutput loop forever, overruns of its output and frame tables, a
    frame countdown that wrapped past zero, reads before index 0 and past
    the phoneme tables, and an unbounded sample position. Text now reaches
    SAM only through samTame and samSay.
